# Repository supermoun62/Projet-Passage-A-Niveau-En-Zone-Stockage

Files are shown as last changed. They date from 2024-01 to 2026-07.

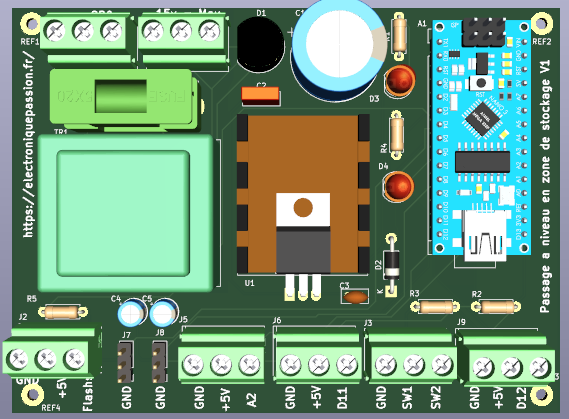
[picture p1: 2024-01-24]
Github_Projet_Passage_a_niveau_zone_stockage_Images/Github_Projet_Passage_a_niveau_zone_stockage_3D.png

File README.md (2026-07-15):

Gerer un passage à niveau en zone de Stockage:

Programmes Arduino:V1 et V2

Librairies Servo.

Liste_Materiel_Passage_A_niveau_Stockage.pdf

Schema_Passage_A_niveau_Stockage Schema_Nano.pdf

Documentations_Passage_A_niveau_Stockage

PCB_Gerber_Passage_A_niveau_Stockage

PCB_PDF_Passage_A_niveau_Stockage

Le fichier Passage_A_niveau_Stockage.pdf contient le détail du projet.

synoptique:
https://github.com/supermoun62/Projet-Passage-A-Niveau-En-Zone-Stockage/blob/main/Github_Projet_Passage_a_niveau_zone_stockage_Images/Github_Projet_Passage_a_niveau_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

PCB 3D
https://github.com/supermoun62/Projet-Passage-A-Niveau-En-Zone-Stockage/blob/main/Github_Projet_Passage_a_niveau_zone_stockage_Images/Github_Projet_Passage_a_niveau_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

PCB
https://github.com/supermoun62/Projet-Passage-A-Niveau-En-Zone-Stockage/blob/main/Github_Projet_Passage_a_niveau_zone_stockage_Images/Github_Projet_Passage_a_niveau_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

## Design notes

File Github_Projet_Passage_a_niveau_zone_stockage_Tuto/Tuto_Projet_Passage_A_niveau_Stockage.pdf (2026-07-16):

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
Passage a niveau en zone de stockage | http://electroniquepassion.fr

### 1 Sur 16

# PROJET

## Commande passage a niveau en zone de stockage

## Arduino – Commande passage a niveau en zone de stockage

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
### 2 Sur 16

Gérer un passage à niveau en zone de stockage.

Contraintes:

Deux capteurs

Obligation de quitter les capteurs en entrée et sortie du passage à niveau.

Le dossier comprend:

Programmes Arduino (V1 et V2).

Schéma de câblage en PDF.

Diverses documentations.

Liste du matériel.

Dossier Kicad en Gerber et PDF.

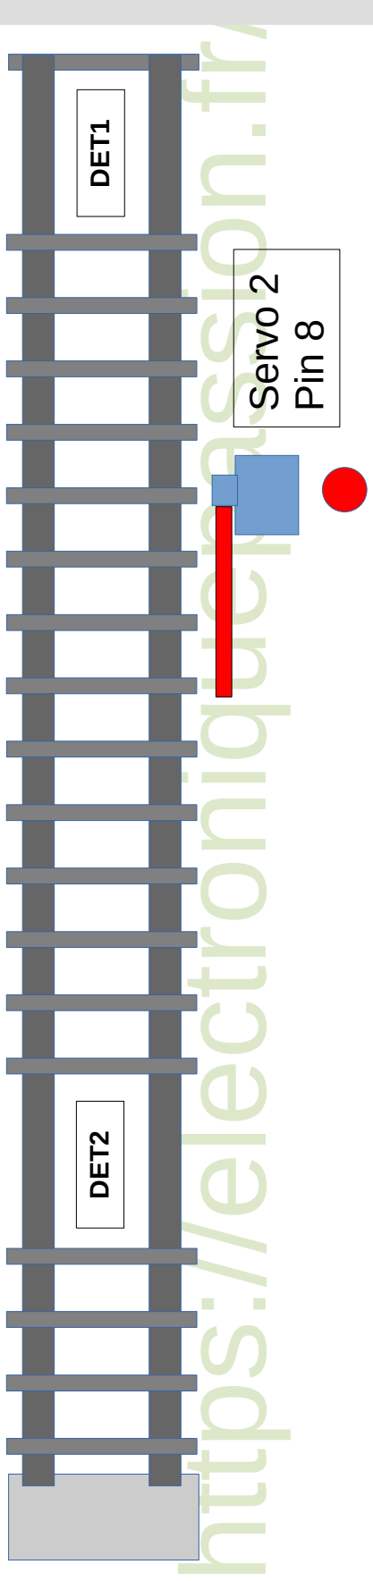
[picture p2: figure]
erv; Pin

### 3 Sur 16

P

o

ur c

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
t, n

e

p

a

s

re

s

t

er s

ur le

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
### 4 Sur 16

P

o

ur c

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
t, n

e

p

a

s

re

s

t

er s

ur le

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
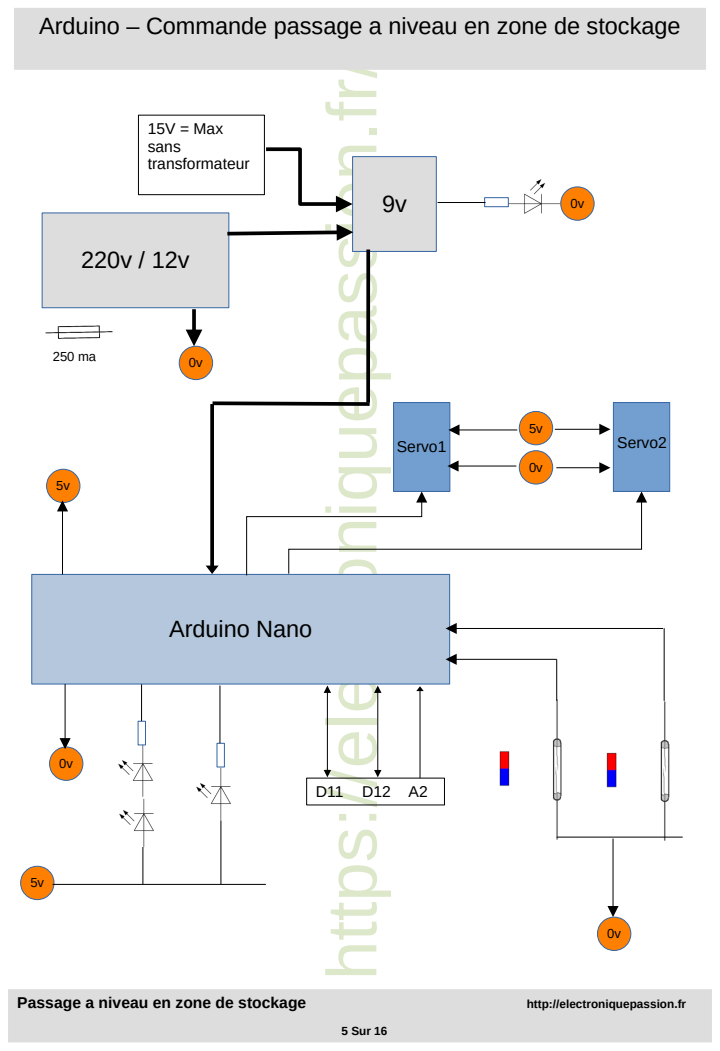
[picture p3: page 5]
5 Sur 16; Arduino Nano; Servo1; Servo2; 15V = Max sans transformateur

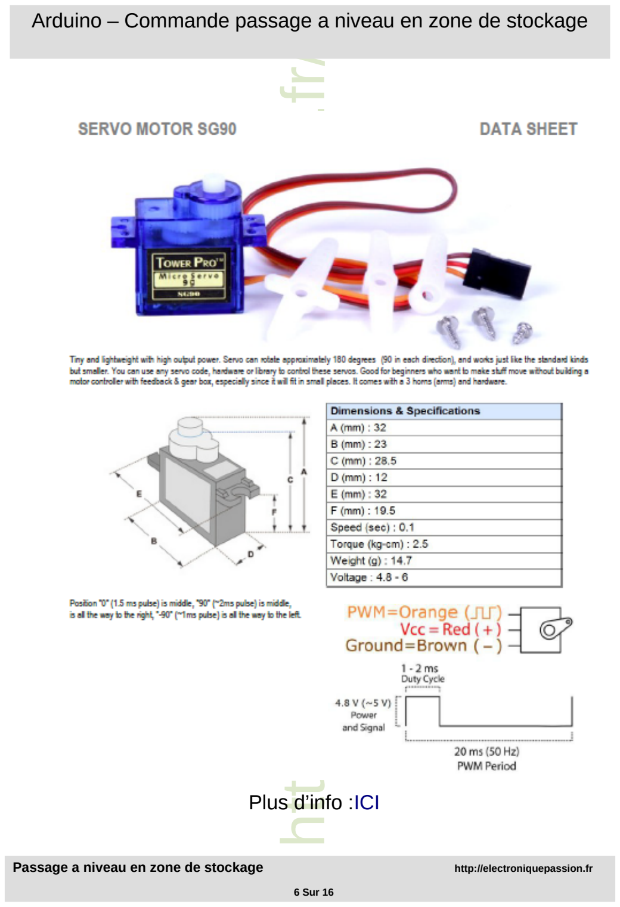
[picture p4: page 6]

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
### 6 Sur 16

Plus d’info :ICI (http://www.ee.ic.ac.uk/pcheung/teaching/DE1_EE/stores/sg90_datasheet.pdf)

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
# q (https://www.arduino.cc/reference/en/libraries/servo/)

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
### 7 Sur 16

Marron | Noir | GND
Rouge | Rouge | +5v
Orange | Jaune | cde

## Câblage SG90

## Librairie Servo

La bibliothèque Servo prend en charge jusqu'à 12 moteurs sur la plupart des cartes Arduino et 48 sur l'Arduino Mega. Sur les cartes autres que la Mega, l'utilisation de la bibliothèque désactive la fonctionnalité analogWrite() (PWM) sur les broches 9 et 10, qu'il y ait ou non un servo sur ces broches.
Sur le Mega, jusqu'à 12 servos peuvent être utilisés sans interférer avec la fonctionnalité PWM ; l'utilisation de 12 à 23 moteurs désactivera le PWM sur les broches 11 et 12.

Plus d’info : ICI

attach()

servo.attach(pin)
servo.attach(pin, min, max)

Attachez la variable servo à une broche. Notez que dans Arduino IDE 0016 et versions antérieures, la bibliothèque Servo prend en charge les servos sur seulement deux broches : 9 et 10.

servo: une variable de type Servo
Pin: le numéro de la broche à laquelle le servo est attaché
Min: min (facultatif) : la largeur d'impulsion, en microsecondes, correspondant à l'angle minimum (0 degré) sur le servo (par défaut : 544)
Max : (optional): the pulse width, in microseconds, corresponding to the maximum (180 degree) angle on the servo (defaults to 2400) (https://www.arduino.cc/reference/en/libraries/servo/)

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
### 8 Sur 16

write() (https://www.arduino.cc/reference/en/libraries/servo/write/)

servo.write(angle)

servo: a variable of type Servo
angle: the value to write to the servo, from 0 to 180

Écrit une valeur sur le servo, contrôlant l'arbre en conséquence. Sur un servo standard, cela définira l'angle de l'arbre (en degrés), déplaçant l'arbre vers cette orientation. Sur un servo à rotation continue, cela définira la vitesse du servo (0 étant la pleine vitesse dans un sens, 180 étant la pleine vitesse dans l'autre et une valeur proche de 90 signifiant aucun mouvement)

writeMicroseconds() (https://www.arduino.cc/reference/en/libraries/servo/writemicroseconds/)

servo.writeMicroseconds(us)

Écrit une valeur en microsecondes (us) sur le servo, contrôlant l'arbre en conséquence. Sur un servo standard, cela définira l'angle de l'arbre. Sur les servos standard, une valeur de paramètre de 1 000 correspond à fond dans le sens inverse des aiguilles d'une montre, 2 000 à fond dans le sens des aiguilles d'une montre et 1 500 au milieu.
A noter que certains constructeurs ne suivent pas cette norme de très près et que les servos répondent souvent à des valeurs comprises entre 700 et 2300. N'hésitez pas à augmenter ces points finaux jusqu'à ce que le servo ne continue plus à augmenter sa portée. Notez cependant que tenter de faire passer un servo au-delà de ses points limites (souvent indiqué par un grognement) est un état à courant élevé et doit être évité.

Les servos à rotation continue répondront à la fonction writeMicrosecond d'une manière analogue à la fonction d'écriture.

read() (https://www.arduino.cc/reference/en/libraries/servo/read/)

servo.read()
Lire l'angle actuel du servo (la valeur passée au dernier appel à write())

attached() (https://www.arduino.cc/reference/en/libraries/servo/attached/)

servo.attached()

Vérifiez si la variable servo est attachée à une broche..

detach() (https://www.arduino.cc/reference/en/libraries/servo/detach/)

servo.detach()

Détachez la variable Servo de sa broche. Si toutes les variables servo sont détachées, alors les broches 9 et 10 peuvent être utilisées pour la sortie PWM avec analogWrite().

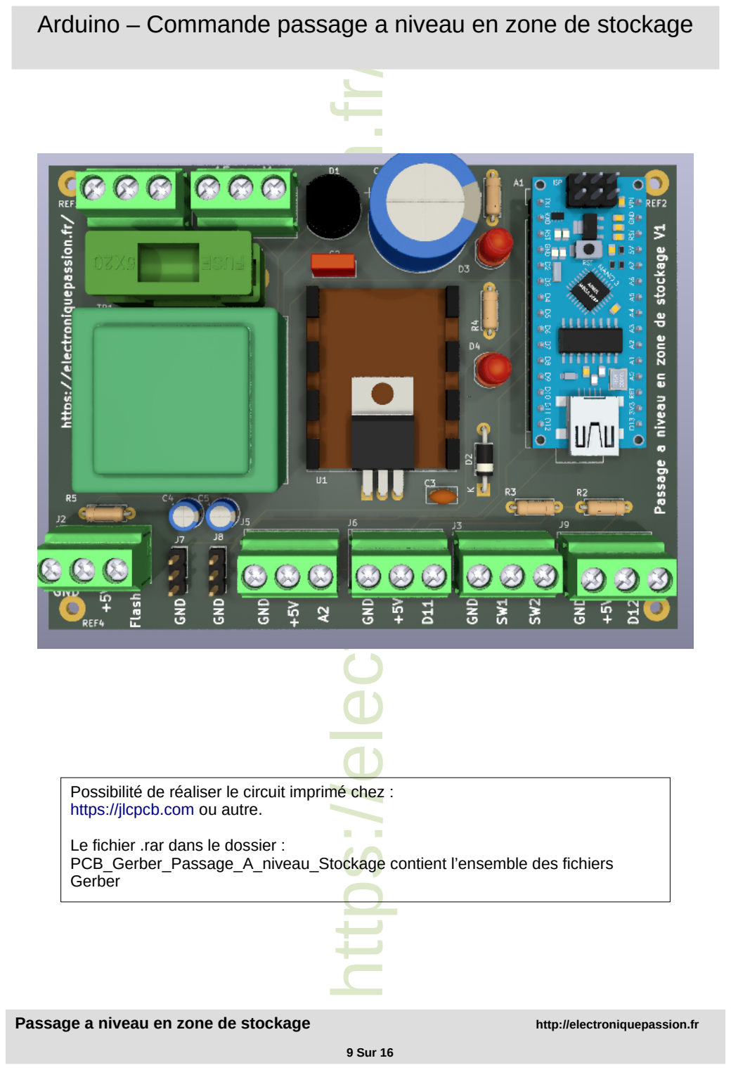
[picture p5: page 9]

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
### 9 Sur 16

Possibilité de réaliser le circuit imprimé chez :
https://jlcpcb.com ou autre.

Le fichier .rar dans le dossier :
PCB_Gerber_Passage_A_niveau_Stockage contient l’ensemble des fichiers Gerber

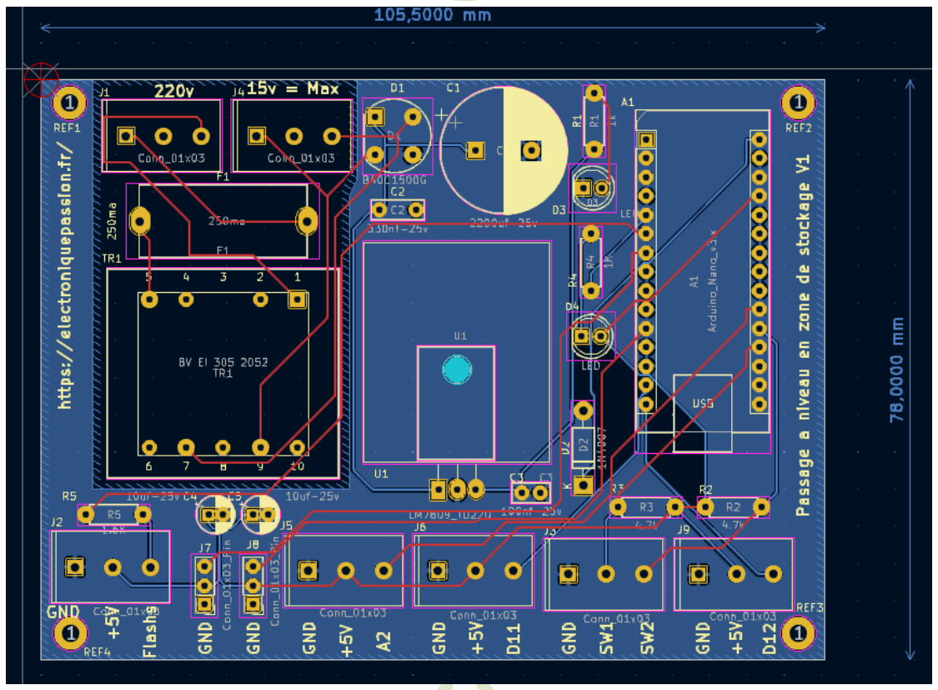
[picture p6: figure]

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
### 10 Sur 16

Mettre de la pâte thermique entre le radiateur et le 7809

Positionner le Nano sur des supports 15br

Référence page suivante

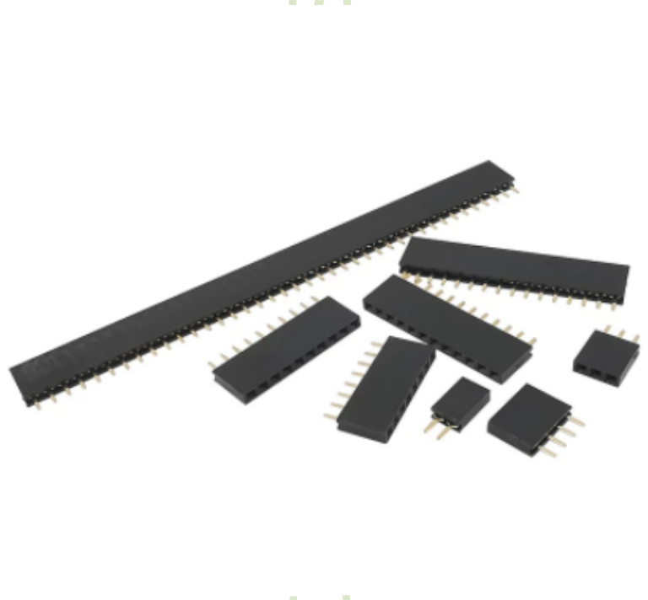
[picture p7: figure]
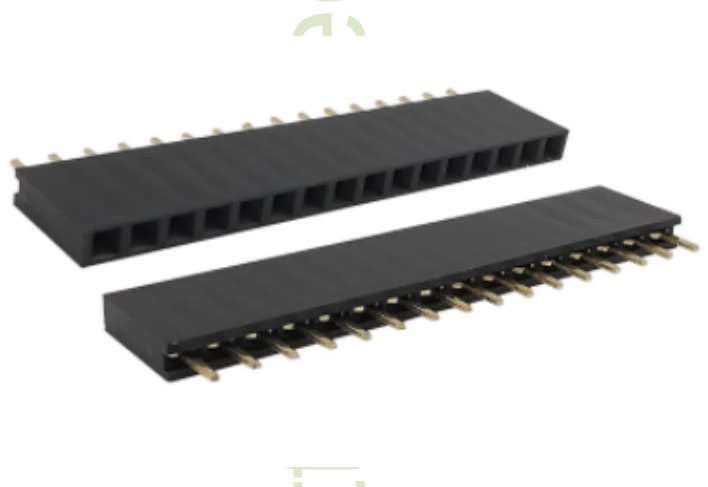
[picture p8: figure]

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
## https://fr.aliexpress.com/item/4000852908837.html? spm=a2g0s.9042311.0.0.41a46c372WkNYm

### 11 Sur 16

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
f (https://github.com/sui77/rc-switch)

r

/

Matériels utilisés:

Contact ILS

Servo Moteur SG90

Sources :

https://www.locoduino.org/spip.php?article62

https://www.volta.ma/comment-controler-les-servomoteurs-avec-arduino/arduino/

https://www.carnetdumaker.net/articles/controler-un-servomoteur-avec-une-carte-arduino-genuino/

https://eskimon.fr/tuto-arduino-602-un-moteur-qui-a-de-la-tête-le-servomoteur

Librairie:
servo (https://github.com/sui77/rc-switch)

### 12 Sur 16

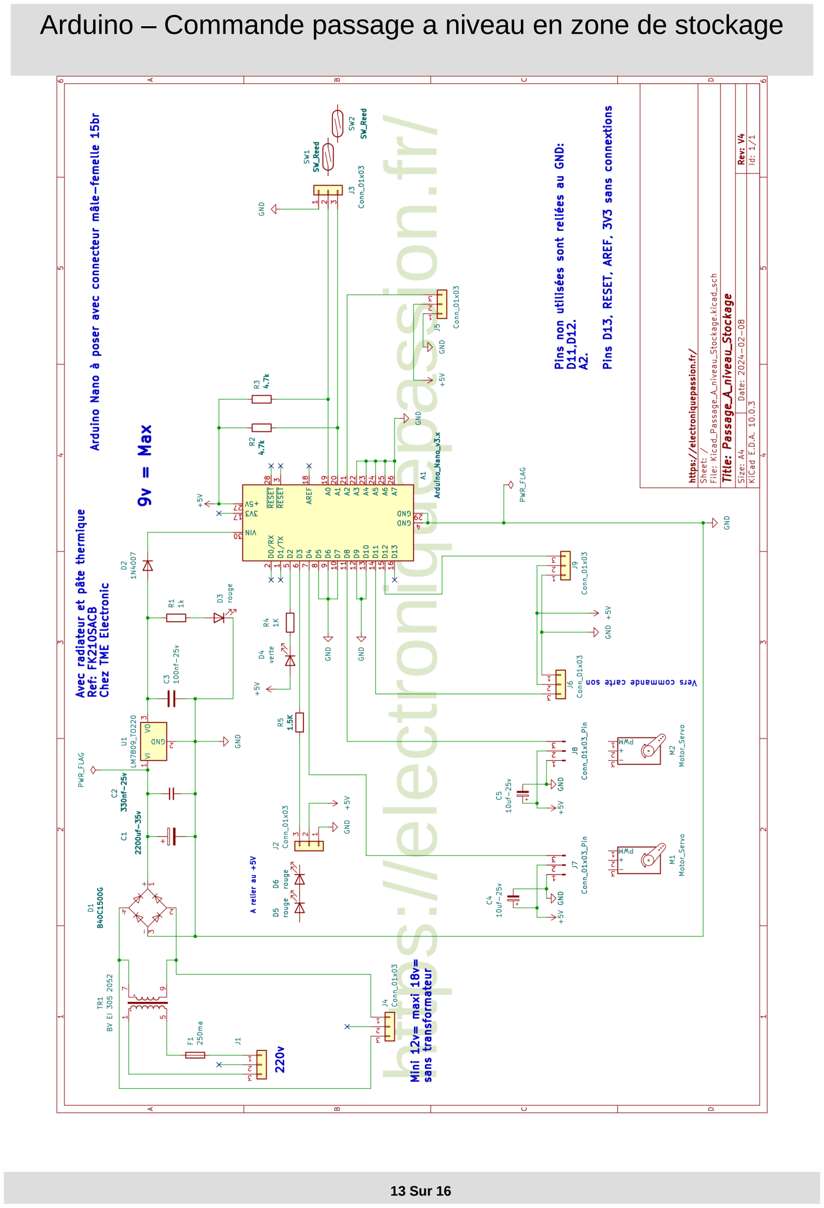
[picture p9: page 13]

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
### 13 Sur 16

Fichier PDF dans le dossier : Schema_Passage_A_niveau_Stockage

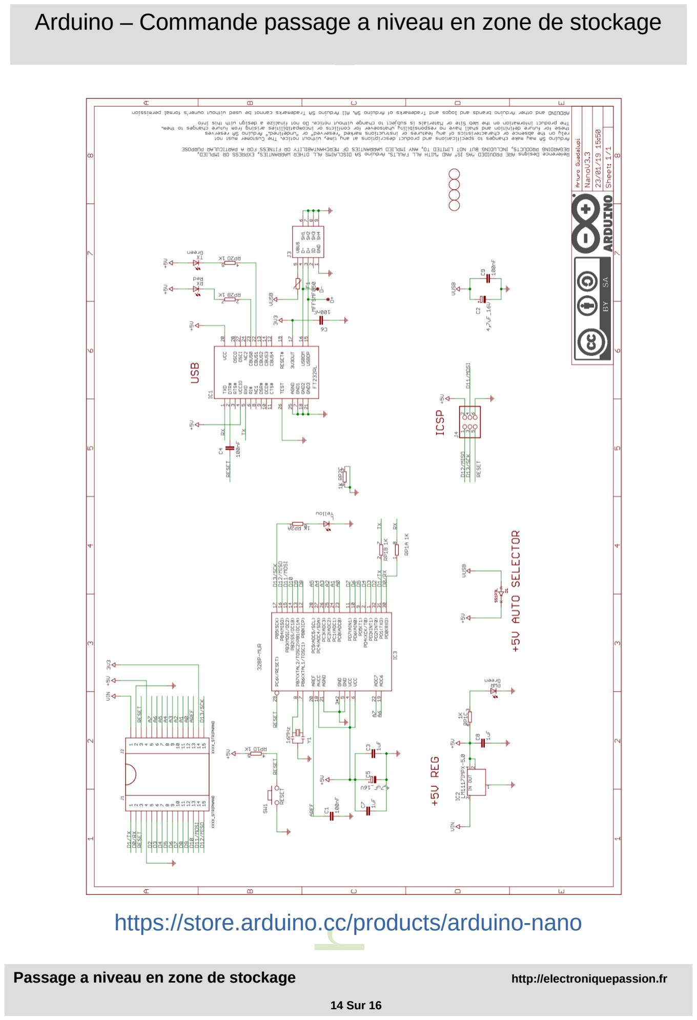
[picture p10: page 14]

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
### 14 Sur 16

## https://store.arduino.cc/products/arduino-nano

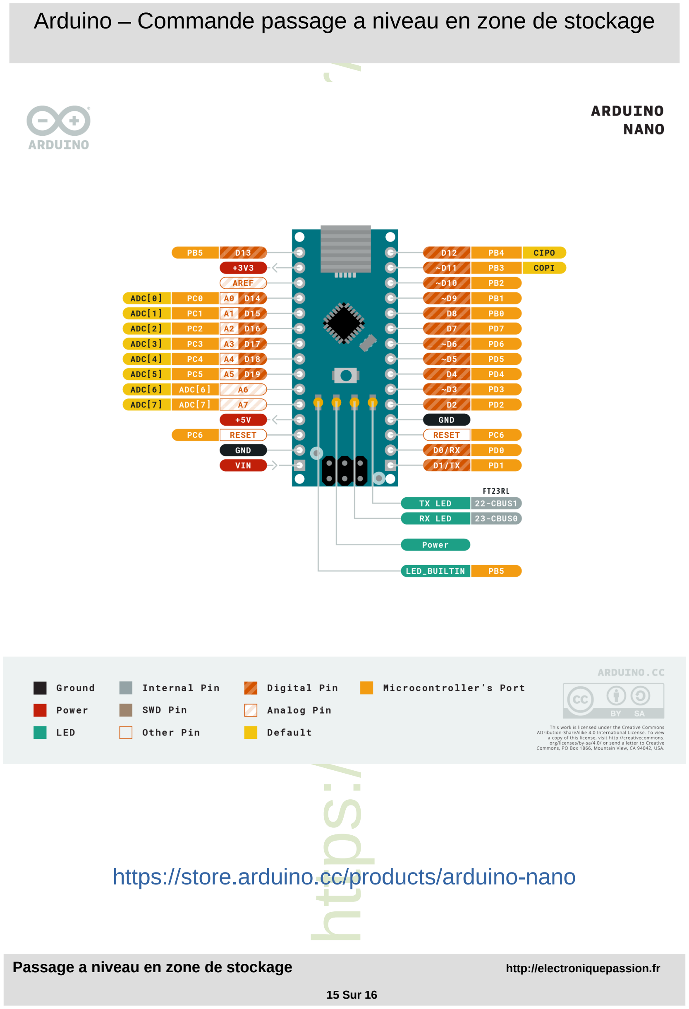
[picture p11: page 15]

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
### 15 Sur 16

## https://store.arduino.cc/products/arduino-nano

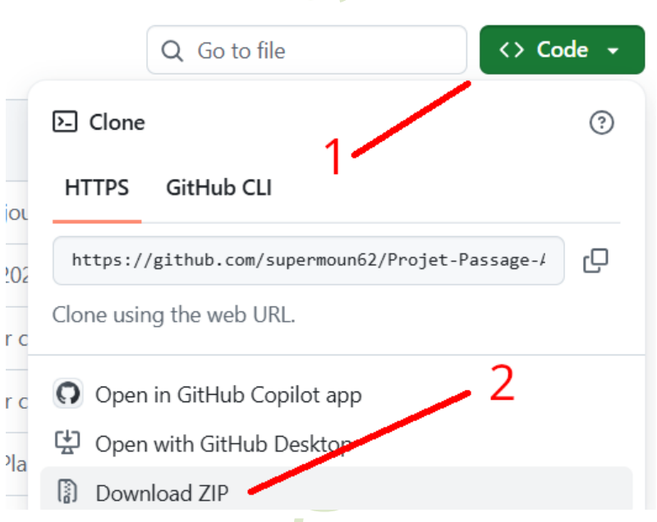
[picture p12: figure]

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
## https://github.com/supermoun62/Projet-Passage-A-Niveau-En-Zone-Stockage

### 16 Sur 16

Lien accès Github (https://github.com/supermoun62/Projet-Passage-A-Niveau-En-Zone-Stockage)

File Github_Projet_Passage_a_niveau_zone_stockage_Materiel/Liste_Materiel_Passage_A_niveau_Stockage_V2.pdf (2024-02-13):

Liste_Materiel_Passage_A_niveau_Stockage | 1 sur 1
# | Reference | Qty | Value | TME-EU | AliExpress

1 | A1 | 1 | Arduino_Nano_v3.x
| Support 15br | 2 | | | https://fr.aliexpress.com/item/4000852908837.html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
2 | C1 | 1 | 2200uf-35v | ED1V222MNN1632
3 | C2 | 1 | 330nf-250v | ECQE2334KF
4 | C3 | 1 | 100nf-25v | CCK-100N
5 | C4, C5 | 2 | 10uf-25v | ECA1EEN100
6 | D1 | 1 | B40C1500G | B40C1500G-E4/51 (https://www.tme.eu/fr/details/b40c1500g-e4_51/redresseurs-monophases-a-diodes-ronds/vishay/)
7 | D2 | 1 | 1N4007 | 1N4007-DC (https://www.tme.eu/fr/details/1n4007-dc/diodes-universelles-tht/dc-components/1n4007/)
8 | D3, D5, D6 | 3 | rouge | N0R01L45
9 | D4 | 1 | verte | N0G02L47 (https://www.tme.eu/fr/details/n0g02l47/diodes-led-tht-rondes/brightek-europe/)
10 | F1 | 1 | 250ma | ZHL77
| | | | ZHL7X-H
11 | J1, J2, J3, J4, J5, J6, J9 | 7 | Conn_01x03 | MKDSN2,5-3-5,08-1888690
12 | J7, J8 | 2 | Conn_01x03_Pin | 826629-3
13 | M1, M2 | 2 | Motor_Servo | SG90
14 | R1 | 1 | 1k | MBB02070C1001FCT00 (https://www.tme.eu/fr/details/mbb02070c1001fct00/resistances-tht/vishay/)
15 | R2, R3 | 2 | 4.7k | MBB02070C4701FCT00 (https://www.tme.eu/fr/details/mbb02070c4701fct00/resistances-tht/vishay/)
16 | R4 | 1 | 1K | MBB02070C1001FCT00 (https://www.tme.eu/fr/details/mbb02070c1001fct00/resistances-tht/vishay/)
17 | R5 | 1 | 1.5K | MBB02070C1501FCT00 (https://www.tme.eu/fr/details/mbb02070c1501fct00/resistances-tht/vishay/)
18 | SW1, SW2 | 2 | SW_Reed
19 | TR1 | 1 | BV EI 305 2052 | BV EI 305 2052
20 | U1 | 1 | LM7809_TO220 | NTE1910
| Refroidisseur | 1 | FK210SACB | FK210SACB

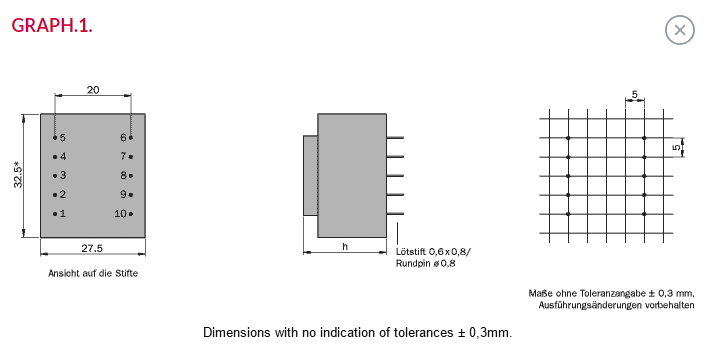
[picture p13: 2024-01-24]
Documentations_Passage_A_niveau_Stockage/BV EI 305 2052.png

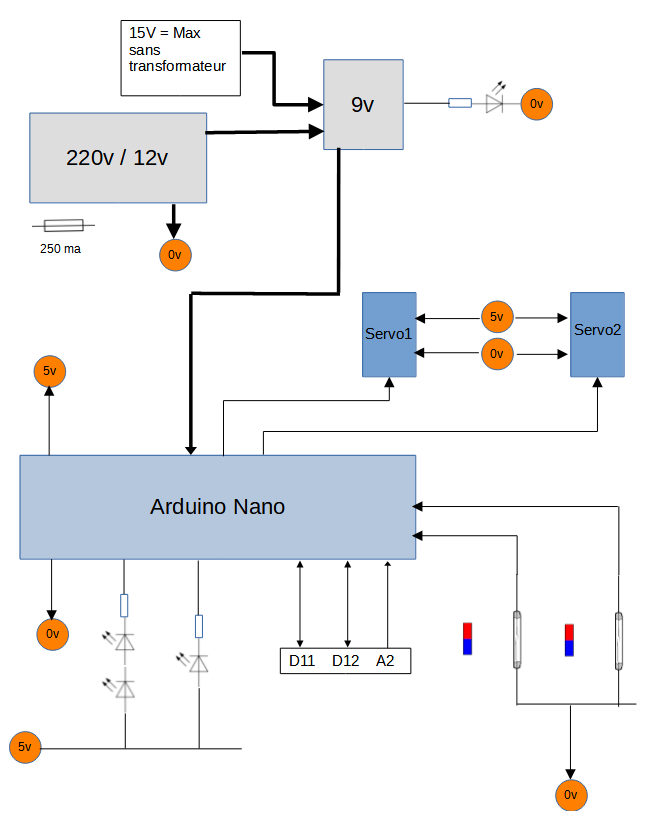
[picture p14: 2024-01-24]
Github_Projet_Passage_a_niveau_zone_stockage_Images/Github_Projet_Passage_a_niveau_zone_stockage_Synoptique.png

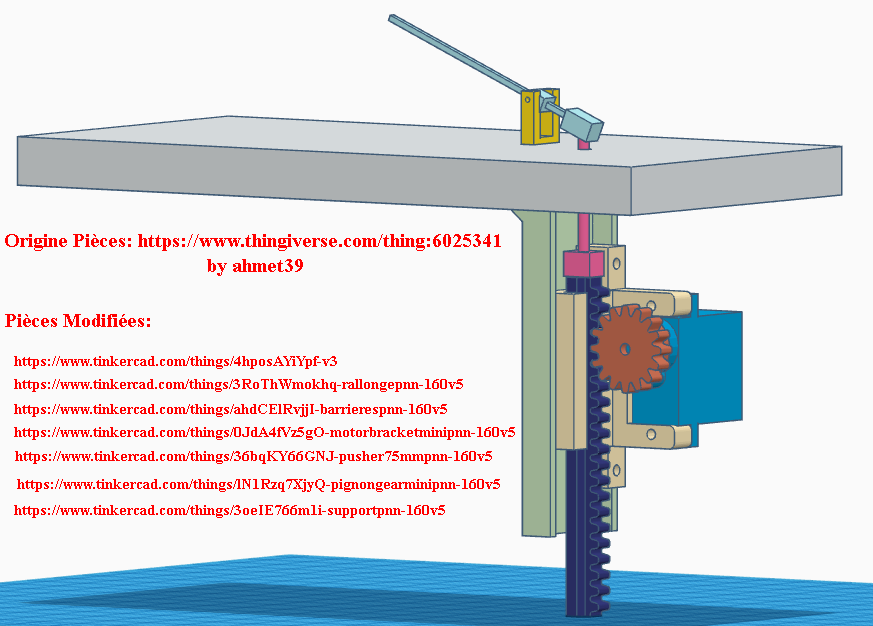
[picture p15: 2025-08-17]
Github_Projet_Passage_a_niveau_zone_stockage_STL/Ensemble_STL_Passage_A_niveau_Stockage_V5.png

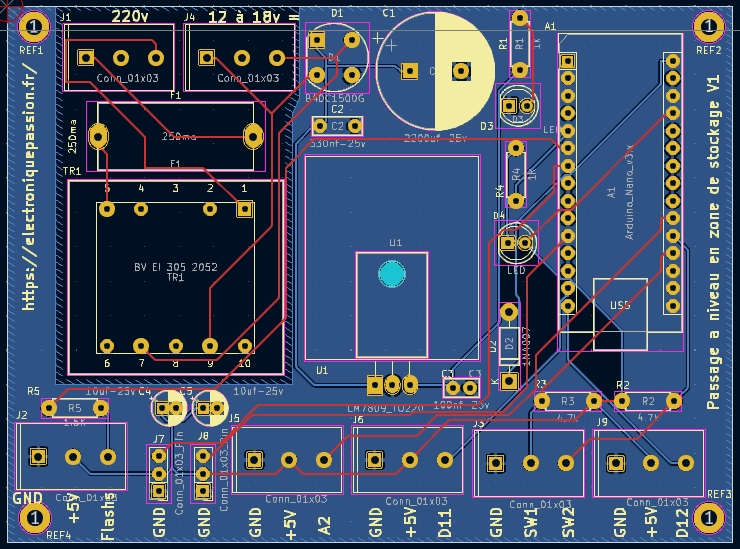
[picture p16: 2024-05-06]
Github_Projet_Passage_a_niveau_zone_stockage_Images/Github_Projet_Passage_a_niveau_zone_stockage_PCB.png

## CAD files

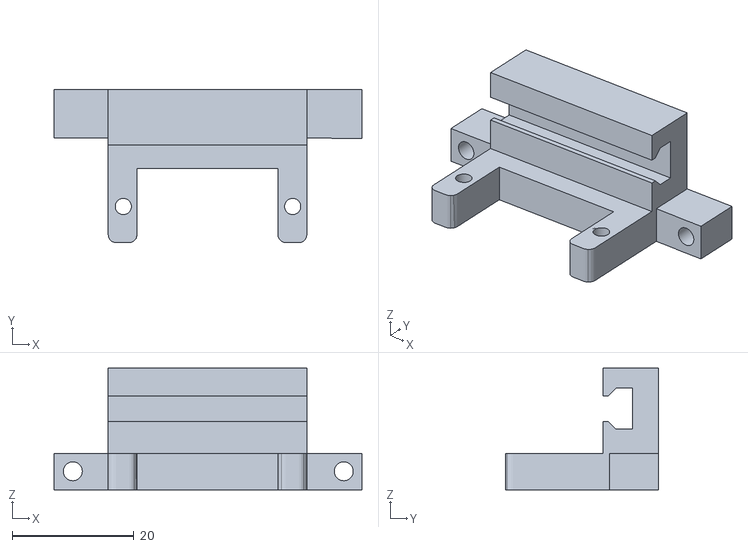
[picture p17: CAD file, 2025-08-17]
Github_Projet_Passage_a_niveau_zone_stockage_STL/Motor_Bracket_Mini_PN_N-160_V5.stl
50.5 x 25.1 x 20.0

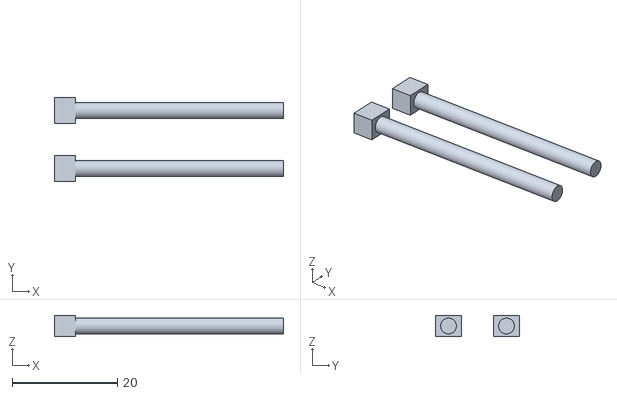
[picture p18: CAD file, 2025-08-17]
Github_Projet_Passage_a_niveau_zone_stockage_STL/Rallonge_PN_N-160_V5.stl
43.5 x 16.0 x 4.00

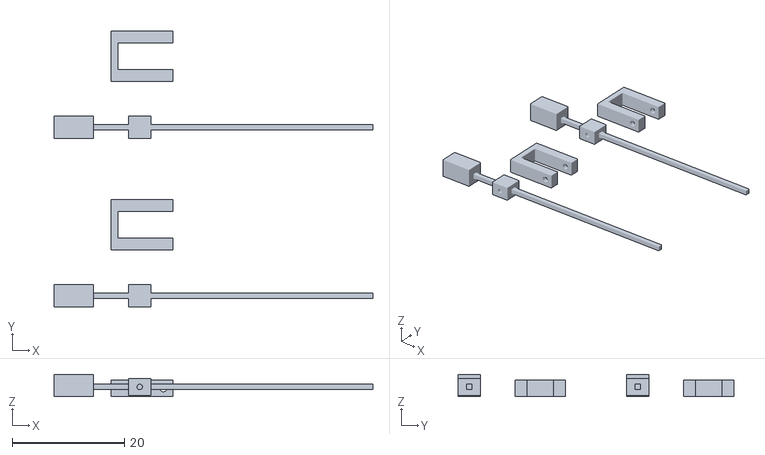
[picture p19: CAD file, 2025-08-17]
Github_Projet_Passage_a_niveau_zone_stockage_STL/Barrieres_PN_N-160_V5.stl
56.8 x 49.2 x 4.00

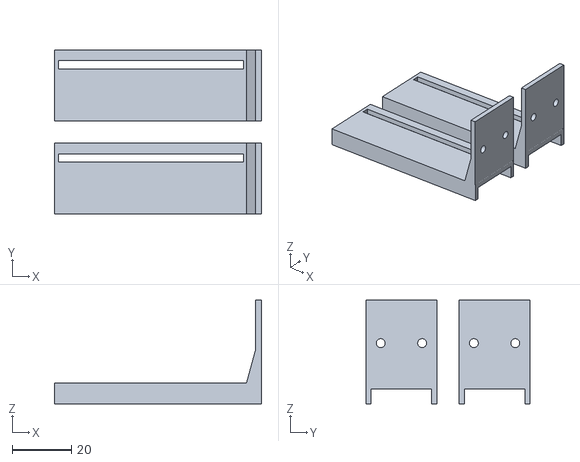
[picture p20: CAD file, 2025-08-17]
Github_Projet_Passage_a_niveau_zone_stockage_STL/Support_PN_N-160_V5.stl
70.0 x 55.5 x 35.0

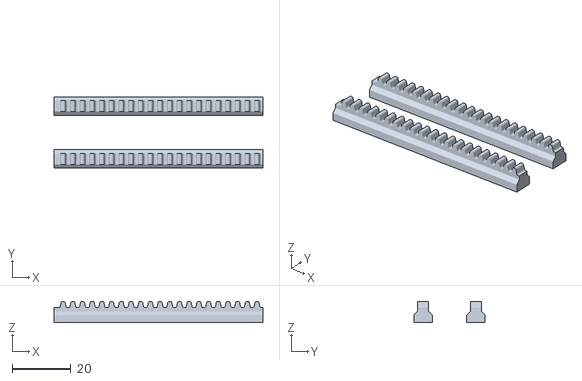
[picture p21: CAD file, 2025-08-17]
Github_Projet_Passage_a_niveau_zone_stockage_STL/Pusher_75mm_PN_N-160_V5.stl
71.2 x 24.4 x 7.20

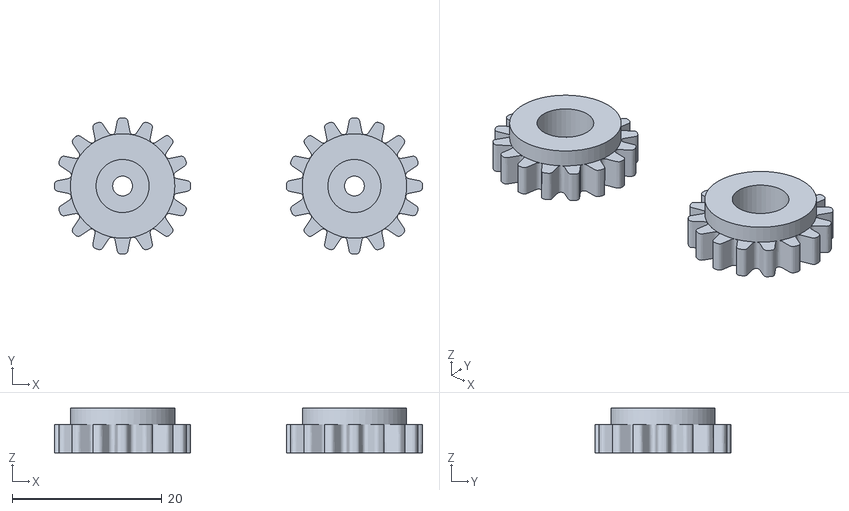
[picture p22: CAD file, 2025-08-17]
Github_Projet_Passage_a_niveau_zone_stockage_STL/Pignon_Gear_Mini_PN_N-160_V5.stl
49.2 x 18.2 x 5.97

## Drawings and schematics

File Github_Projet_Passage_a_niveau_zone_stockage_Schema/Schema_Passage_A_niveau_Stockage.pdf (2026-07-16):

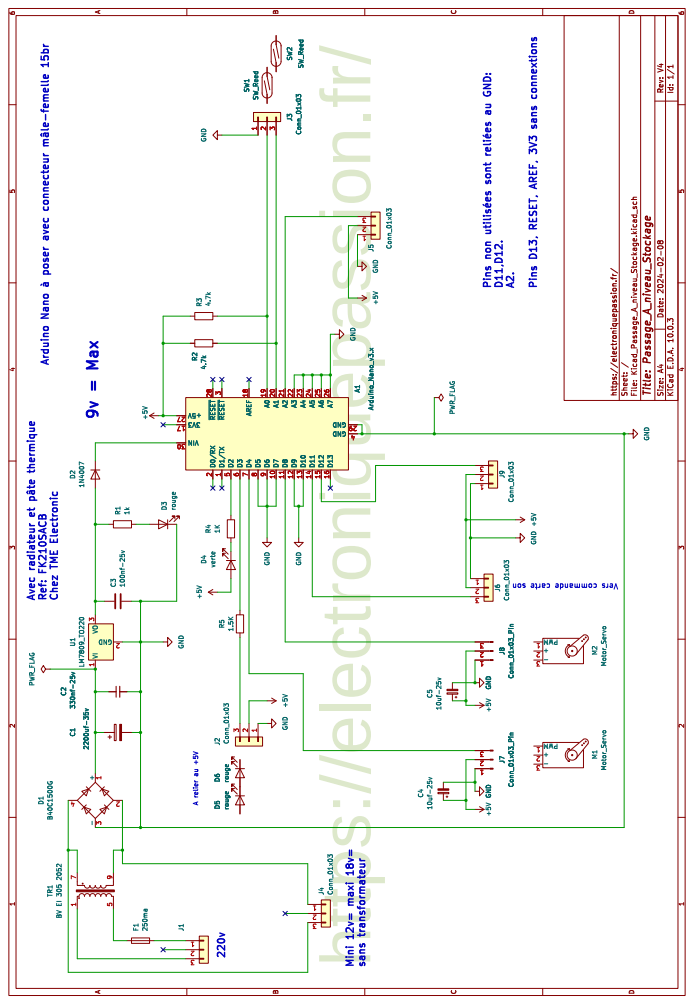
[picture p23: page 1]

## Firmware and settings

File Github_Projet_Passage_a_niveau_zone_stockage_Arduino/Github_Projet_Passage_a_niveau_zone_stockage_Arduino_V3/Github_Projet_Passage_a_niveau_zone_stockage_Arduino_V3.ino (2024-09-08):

/* Synopsis: Passage a niveau avant stockage
   Carte   : Arduino Nano
   Capteur : Capteurs ILS  
             
  Biblio:  Servo.h 
             
  Source:  https://www.locoduino.org/spip.php?article262
           https://www.locoduino.org/spip.php?article62
           https://www.volta.ma/comment-controler-les-servomoteurs-avec-arduino/arduino/
           https://www.carnetdumaker.net/articles/controler-un-servomoteur-avec-une-carte-arduino-genuino/
           https://eskimon.fr/tuto-arduino-602-un-moteur-qui-a-de-la-tête-le-servomoteur
           https://zestedesavoir.com/tutoriels/686/arduino-premiers-pas-en-informatique-embarquee/747_le-mouvement-grace-aux-moteurs/3438_un-moteur-qui-a-de-la-tete-le-servomot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
           
   https://electroniquepassion.fr/ 
   C.Mercier  62128 Boiry-Becquerelle  
*/
//-----------------------------------------------------------------
#include <Servo.h>
Servo monServo1;
Servo monServo2;
int vitesse;
int angle1;
int angle2;
/*!!!!!!!!!!!!!!!!!!!!!!!!!!!!!!!!!!!!!!!!!!!!!!!!!!!!!!!!!!!!!!!!!!!!!!!!!!!!!!!
544µs donnera un angle de 0° et une valeur de 2400µs donnera un angle de 180°.
A verifier avec le datasheet du servomoteur
!!!!!!!!!!!!!!!!!!!!!!!!!!!!!!!!!!!!!!!!!!!!!!!!!!!!!!!!!!!!!!!!!!!!!!!!!!!!!!!*/
const int ANGLE_MIN1  = 1400;//  Modifie le 26/12/2023
const int ANGLE_MAX1 = 1998;// 2000 Modifie le 07/08/2024
const int ANGLE_MIN2  = 1400;// 1300 Modifie le 07/08/2024
const int ANGLE_MAX2 = 1998;// 2000 Modifie le 07/08/2024
const int ANGLE1_SOUSTENSION = 1998;// 1500 Modifie le 07/08/2024
const int ANGLE2_SOUSTENSION = 1998;// 1500 Modifie le 07/08/2024

bool cdeServos;

const int DET1 = A0;
const int DET2 = A1;

const byte LED_ZONE_OCCUPEE = 13;// Utilisee pour informtion zone occupee
bool memDet1;
bool memDet2;

unsigned long compteurTempsFermetureBarrieres = 0;
unsigned long compteurTempsOuvertureBarrieres = 0;
int retardFermetureBarrieres = 800;//  Temps avant fermeture en ms
int retardOuvertureBarrieres = 800;//  Temps avant ouverture en ms

bool fermetureBarrieres = 0;
bool ouvertureBarrieres = 0;
bool zoneOccupee = 0;// Zone entre les deux capteurs
int etatDet1 = 1023;
int etatDet2 = 1023;

const byte FLASH= 3;// Port PD
const byte DEL_SW1_SW2 = 2;
unsigned long compteurTempsLeds = 0; //  Variable pour compter le temps pour faire clignoter à intervale fixe les leds
bool flipFlop = 0;// Allumage Leds

unsigned long tempsCourant = 0;
unsigned long tempsPULS_D11 = 500;
const byte PULS_D11 = 11;// Pilotage circuit son
bool memPulsD11 = 0; 
//--------------------------------------------
void setup()
{
monServo1.attach(4);// Port PD
monServo2.attach(8);// Port PB
angle1 = ANGLE_MIN1;
angle2 = ANGLE_MIN2;
vitesse = 4;
/*!!!!!!!!!!!!!!!!!!!!!!!!!!!!!!!!!!!!!!!!!!!!!!!!!!!!!!!!!!!!!!!!!!!!!!!!!!!!!!!
544µs donnera un angle de 0° et une valeur de 2400µs donnera un angle de 180°.
A verifier avec le datasheet du servomoteur
!!!!!!!!!!!!!!!!!!!!!!!!!!!!!!!!!!!!!!!!!!!!!!!!!!!!!!!!!!!!!!!!!!!!!!!!!!!!!!!*/
monServo1.writeMicroseconds(ANGLE1_SOUSTENSION);
monServo2.writeMicroseconds(ANGLE2_SOUSTENSION);

pinMode(DET1, INPUT);// Detecteur avant passage a niveau
pinMode(DET2, INPUT);// Detecteur apres passage a niveau
pinMode(FLASH, OUTPUT);
pinMode(DEL_SW1_SW2, OUTPUT);
pinMode(LED_ZONE_OCCUPEE, OUTPUT);
pinMode(PULS_D11, OUTPUT);

digitalWrite(FLASH,HIGH);
digitalWrite(DEL_SW1_SW2,HIGH);
digitalWrite(LED_ZONE_OCCUPEE,LOW);
digitalWrite(PULS_D11, HIGH);
memDet1 = 0;
memDet2 = 1;

Serial.begin(9600); 
delay(5000);

}//FIN_SETUP
//--------------------------------------------
void loop()
{
etatDet1 = analogRead(DET1);
etatDet2 = analogRead(DET2);
//--------------------------------------------
  if(etatDet1 <= 512 && zoneOccupee == 0 && memDet2 == 1)
    {
      memDet1 = 1;
      memDet2 = 0;
      zoneOccupee = 1;
    }
//--------------------------------------------    
  if(etatDet2 <= 512 && zoneOccupee == 0 && memDet1 == 1)
    {
      memDet2 = 1;
      memDet1 = 0;
      zoneOccupee = 1;
    }
//--------------------------------------------
  if ((etatDet1 <= 512 && memDet1 == 1) || (etatDet2 <= 512 && memDet2 == 1) )
    {         
        fermetureBarrieres = 1;
        compteurTempsFermetureBarrieres = millis();         
    }
  if(fermetureBarrieres == 1)
    {
       if((millis()-compteurTempsFermetureBarrieres) >= retardFermetureBarrieres)
        { 
          fermetureBarrieres = 0; 
          cdeServos = 1; 
        }  
    }
//--------------------------------------------
  if ((etatDet2 <= 512 && zoneOccupee == 1 && memDet1 == 1) || (etatDet1 <= 512 && zoneOccupee == 1 && memDet2 == 1))
    {         
        ouvertureBarrieres = 1;
        compteurTempsOuvertureBarrieres = millis();         
    }
  if(ouvertureBarrieres == 1)
    {
       if((millis()-compteurTempsOuvertureBarrieres) >= retardOuvertureBarrieres)
        { 
          ouvertureBarrieres = 0; 
          zoneOccupee = 0;
          cdeServos = 0;
        }  
    }
//--------------------------------------------
  if(zoneOccupee == 1) 
    {  
      digitalWrite(LED_ZONE_OCCUPEE,HIGH);
      Signal();// appel fonction Leds
    }      
  else
    {
      digitalWrite(LED_ZONE_OCCUPEE,LOW);
      digitalWrite(FLASH,HIGH);
    } 
//--------------------------------------------
  if(cdeServos == 1)
    {
      //ServosFermeture1();//  Modifie le 26/12/2023
      //ServosFermeture2();//  Modifie le 26/12/2023
      ServosOuverture1();
      ServosOuverture2();
      delay(2);
    }
//--------------------------------------------
  if(cdeServos == 0)
    {
      //ServosOuverture1();//  Modifie le 26/12/2023
      //ServosOuverture2();//  Modifie le 26/12/2023
      ServosFermeture1();
      ServosFermeture2();
      delay(2);
    }
//--------------------------------------------
if(etatDet1 < 512 || etatDet2 < 512) 
  {
    digitalWrite(DEL_SW1_SW2,LOW);
  }  
else
  {
    digitalWrite(DEL_SW1_SW2,HIGH);
  }
pulsD11();  
//--------------------------------------------
//Serial.print(etatDet1);
//Serial.print("\t");
//Serial.print(etatDet2);
//Serial.print("\t");
//Serial.print(memDet1);
//Serial.print("\t");
//Serial.print(memDet2);
//Serial.print("\t");
Serial.print(cdeServos);
Serial.print("\t");
Serial.print("\t");
Serial.print(angle1);
Serial.print("\t");
Serial.println(angle2);
//Serial.print("\t");
//Serial.println(zoneOccupee);
}//FIN_LOOP
//--------------------------------------------
void ServosFermeture1()
{
monServo1.writeMicroseconds(angle1);
/* calcule le nouvel angle */
angle1 = angle1 + vitesse;
 
  if (angle1 > ANGLE_MAX1)
    {
      angle1 = ANGLE_MAX1;
    }
//delay(2);    
}  
//--------------------------------------------
void ServosOuverture1()
{
monServo1.writeMicroseconds(angle1);
/* calcule le nouvel angle */
angle1 = angle1 - vitesse;

  if (angle1 < ANGLE_MIN1)
    {
      angle1 = ANGLE_MIN1;
    }
//delay(2);    
}  
//--------------------------------------------
void ServosFermeture2()
{
monServo2.writeMicroseconds(angle2);
/* calcule le nouvel angle */
angle2 = angle2 + vitesse;
 
  if (angle2 > ANGLE_MAX2)
    {
      angle2 = ANGLE_MAX2;
    }
//delay(2);    
}  
//--------------------------------------------
void ServosOuverture2()
{
monServo2.writeMicroseconds(angle2);
/* calcule le nouvel angle */
angle2 = angle2 - vitesse;

  if (angle2 < ANGLE_MIN2)
    {
      angle2 = ANGLE_MIN2;
    }
//delay(2);    
}  
//------Fonction leds-------
void Signal()
{
  if (millis() > compteurTempsLeds + 500)
    {
      compteurTempsLeds = millis();
        if (flipFlop == false)
         {
          flipFlop = true;
          digitalWrite(FLASH,HIGH);         
         } 
        else
         {
          flipFlop = false;
          digitalWrite(FLASH,LOW);          
         }
    }
}
void pulsD11()
{
  if(zoneOccupee == 1 && memPulsD11 == 0)
  {
    digitalWrite(PULS_D11, LOW);
    memPulsD11 = 1;
    tempsCourant = millis();
  }  
  if(millis() - tempsCourant >= tempsPULS_D11)
    {
      digitalWrite(PULS_D11, HIGH);         
    }      
  if(zoneOccupee == 0)
    {
      memPulsD11 = 0;    
    }  
}

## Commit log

2024-01-24 C. Mercier 24/01/2024
    [Kicad_Passage_A_niveau_Stockage-B_Adhesive.gbr, Kicad_Passage_A_niveau_Stockage-B_Courtyard.gbr, Kicad_Passage_A_niveau_Stockage-B_Cu.gbr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]
2024-02-08 C. Mercier Suppression fichier Liste_Materiel_Passage_A_niveau_Stockage_V1.ods
    [Liste_Materiel_Passage_A_niveau_Stockage_V1.ods]
2024-05-06 C. Mercier mise à jour fichiers Gerber et Pdf Kicad
    [Kicad_Passage_A_niveau_Stockage-B_Adhesive.gbr, Kicad_Passage_A_niveau_Stockage-B_Courtyard.gbr, Kicad_Passage_A_niveau_Stockage-B_Cu.gbr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]
2024-09-08 C. Mercier 08/09/2024 Mise à jour fichier Passage_A_niveau_Stockage.pdf, Passage_A_niveau_Stockage_V3.ino
    [Motor_Bracket_Mini_2_V2.stl, Passage à niveau N_V2.stl, Rallonge_Passage_A_Niveau_N_V2.stl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]
2025-08-17 Mise à jour dossier STL C. Mercier 17/08/2025
    [Barrieres_PN_N-160_V5.stl, Motor_Bracket_Mini_2_V2.stl, Motor_Bracket_Mini_PN_N-160_V5.stl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]
2026-07-14 Mise à jour dossier complet supermoun62 14/07/2026
    [Barrieres_PN_N-160_V5.stl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]
2026-07-16 Mise à jour fichiers Gerber, Tuto supermoun62 16/07/2026
    [Kicad_Passage_A_niveau_Stockage-B_Adhesive.gbr, Kicad_Passage_A_niveau_Stockage-B_Courtyard.gbr, Kicad_Passage_A_niveau_Stockage-B_Cu.gbr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]
